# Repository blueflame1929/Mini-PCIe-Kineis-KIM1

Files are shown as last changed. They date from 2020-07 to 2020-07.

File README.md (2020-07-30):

# Mini PCI Express Card / Kinéis KIM1 Satellite Transmitter

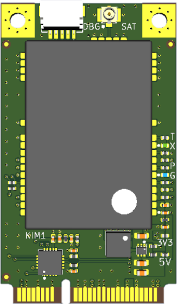
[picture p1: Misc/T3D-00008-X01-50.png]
T3D-00008-X01-50
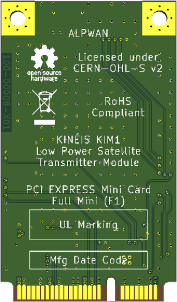
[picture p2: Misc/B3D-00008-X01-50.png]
B3D-00008-X01-50
  

This card is a satellite modem that targets IoT applications. Some IoT applications may require 24/7 worldwide coverage, and cellular networks are not suitable since they may not provide coverage in remote locations, at sea, or at altitude. The only solution in that case is to go with satellite communication through thank to networks such as the ones provided by Kinéis. Available everywhere, low power consumption, simple, reliable and affordable.

Kinéis KIM1 is a low power transmitter module based on ARGOS-2 technology and fully-certified by the CNES. It enables communication with all the Kineis-Argos satellites to provide satellite connectivity and localization for IoT devices. The use of ARGOS RF signals and protocols ensures very low power consumption when sending data from anywhere around the world.

This card makes it easy to add a satellite modem to your projects thanks to it’s mini PCIe form factor and USB 2.0 interface.

more informations see www.kineis.com

# Key features and specifications

BRD-00008-X01-Block-Diagram

- Kinéis KIM1 Satellite Transmitter
- Small lightweight module for embedded applications
- Available everywhere
- RF output power capabilities up to 1W
- Low power consumption
- Frequency range 399.910 - 401.680MHz
- UART AT command interface
- Host interface : USB 2.0 via Mini PCIe socket
- Antenna : external via µ.FL connector (50Ω)

- Power Supply Voltage : +3.3V +/-5%
- Operating Current : 1.2A Transmit
- Form Factor : Mini PCI Express, full size
- Dimensions : 50.95 x 30.00 x 4.15mm
- Weight : TBD
- Operating Temperature Range : -20°C/+55°C
- Storage Temperature Range : -40°C/+85°C
- Humidity : 10% to 90%, non condensing

# Repository Contents

- /documentation : integration manual (with AT commands)
- /hardware : KiCad design files (BRD-00008-X01.zip)
- /hardware/ASY : ASY-00008-X01.zip --> send it to your assembly house
- /hardware/Datasheets
- /hardware/PCB : PCB-00008-X01.zip --> sent it to your pcb manufacturer
- /hardware/SCH : SCH-00008-X01 --> engineering team 

# License information

This product is open source.

Please review the LICENSE.md file for license information.

Distribute as-is, no warranty is given.

# Support

If you have some questions, please contact support(at)alpwan.fr

kicad_logo_small

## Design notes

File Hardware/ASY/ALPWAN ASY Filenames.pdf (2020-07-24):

ALPWAN ASY Filenames.xlsx

Name | Kicad file name or layer name | ALPWAN file name
Top Assembly | F.Fab | TAY-XXXXX-XXX.pdf
Top Solder Paste | xxxx-F_Paste.gbr for the component-side solder paste | TSP-XXXXX-XXX.gbr
Top Placement File | xxxx-top.pos | TPF-XXXXX-XXX.txt
Placement File | xxxx-all.pos | PFE-XXXXX-XXX.txt
Bottom Placement File | xxxx.bottom.pos | BPF-XXXXX-XXX.txt
Bottom Solder Paste | xxxx-B_Paste.gbr for the copper-side solder paste | BSP-XXXXX-XXX.gbr
Bottom Assembly | B.Fab | BAY-XXXXX-XXX.pdf
Schematic | n/a | SCH-XXXXX-XXX.pdf
Bill Of Materials | xxxx.csv (convert to Excel) | BOM-XXXXX-XXX.xlsx
Bill Of Materials | Also available in PDF | BOM-XXXXX-XXX.pdf
Board Mechanical Drawing | Dwgs.User | BMD-XXXXX-XXX.pdf
Top 3D View | n/a | T3D-XXXXX-XXX.png
3D View | n/a | 3DV-XXXXX-XXX.png
Bottom 3D View | n/a | B3D-XXXXX-XXX.png
GERBER file format: | The format used by KiCad Pcbnew is RS274X 4.6, Metric, Leading zero omitted, Abs
20/07/2019 | 1 / 1

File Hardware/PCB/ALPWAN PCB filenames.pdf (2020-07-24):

ALPWAN PCB filenames.xlsx

Layer | Kicad file name or layer name | ALPWAN file name
Top Solder Paste | xxxx-F_Paste.gbr for the component-side solder paste | TSP-XXXXX-XXX.gbr
Top Silk Screen | xxxx-F_SilkS.gbr for the component-side silkscreen markings | TSS-XXXXX-XXX.gbr
Top Solder Mask | xxxx-F_Mask.gbr for the component-side solder mask | TSM-XXXXX-XXX.gbr
Top | xxxx-F_Cu.gbr for the component side | TOP-XXXXX-XXX.gbr
Internal 1 | xxxx-In1.Cu.gbr | IL1-XXXXX-XXX.gbr
Internal 2 | xxxx-In2.Cu.gbr | IL2-XXXXX-XXX.gbr
Internal n | xxxx-Inn.Cu.gbr | ILn-XXXXX-XXX.gbr
Bottom | xxxx-B_Cu.gbr for the copper side | BOT-XXXXX-XXX.gbr
Bottom Solder Mask | xxxx-B_Mask.gbr for the copper-side solder mask | BSM-XXXXX-XXX.gbr
Bottom Silk Screen | xxxx-B_SilkS.gbr for the copper-side silkscreen markings | BSS-XXXXX-XXX.gbr
Bottom Solder Paste | xxxx-B_Paste.gbr for the copper-side solder paste | BSP-XXXXX-XXX.gbr
GERBER file format: | The format used by KiCad Pcbnew is RS274X 4.6, Metric, Leading zero omitted, Abs
Drill File | xxxx.drl | DRL-XXXXX-XXX.exc
Drill Map | xxxx-drl_map.pdf | MDD-XXXXX-XXX.pdf
Drill Report | xxxx-drl.rpt | DRL-XXXXX-XXX.rpt
EXCELLON file format : | The format used by KiCad Pcbnew is EXCELLON 3.3, Metric, Leading zero omitted, Abs
PCB Characteristics | see MDD-XXXXX-XXX.pdf
PCB Stack_Up | see MDD-XXXXX-XXX.pdf
Controlled Impedance | Kicad PCB Calculator | IMP-XXXXX-XXX.docx
Controlled Impedance | Also available in PDF | IMP-XXXXX-XXX.pdf
20/07/2019 | 1 / 1

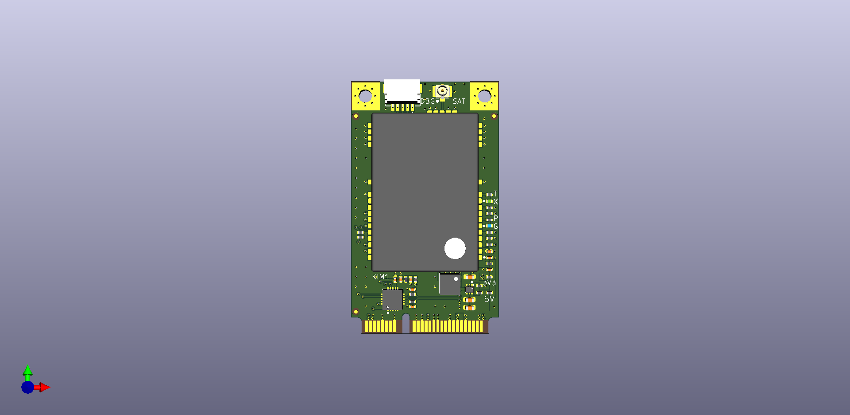
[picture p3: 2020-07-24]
Hardware/ASY/T3D-00008-X01.png

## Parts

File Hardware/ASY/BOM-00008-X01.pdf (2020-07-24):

ALPWAN | PCI Express Mini Card / Kinéis KIM1 | BOM-00008-X01.xlsx
Internal P/N | Quantity Per PCB | References | Description | Manufacturer | Manufacturer P/N
100-00008-X01 | 1 | PCB1 | PCB, Material : FR4 150 TG, Layers : 4 , Dimension : 30.00 x 50.95 mm, Thickness : 1.00 mm, Finition : Chemical NI/Au | TBD | TBD
105-00001-M01 | 4 | R1 R7 R10 R13 | Thick Film Chip Resistor 0R, Jumper, 0.1W, 50V, 1A, -55°C/+155°C, SMD 1005M | PANASONIC | ERJ-2GE0R00
105-00002-M01 | 2 | R2-R3 | Thick Film Chip Resistor 27R, ±1%, 0.1W, 50V, ±100ppm/°C, -55°C/+155°C, SMD 1005M | PANASONIC | ERJ-2RKF27R0
105-00006-M01 | 3 | R5 R9 R15 | Thick Film Chip Resistor 100K, ±1%, 0.1W, 50V, ±100ppm/°C, -55°C/+155°C, SMD 1005M | PANASONIC | ERJ-2RKF1003
105-00050-M01 | 3 | R4 R12 R16 | Thick Film Chip Resistor 665R, ±1%, 0.1W, 50V, ±100ppm/°C, -55°C/+155°C, SMD 1005M | PANASONIC | ERJ-2RKF6650
110-00001-I01 | 2 | C5 C8 | Ceramic Chip Capacitor 10µF, ±20%, 10V, X5R, -55°C/+85°C, SMD 1005M | SAMSUNG | CL05A106MP8NUB8
110-00009-M01 | 2 | C4 C7 | Ceramic Chip Capacitor 100nF, ±10%, 16V, X7R, -55°C/+125°C, SMD 1005M | MURATA | GRM155R71C104KA88
110-00010-M01 | 2 | C3 C6 | Ceramic Chip Capacitor 10nF, ±10%, 25V, X7R, -55°C/+125°C, SMD 1005M | MURATA | GRM155R71E103KA01
110-00024-M01 | 2 | C1-C2 | Ceramic Chip Capacitor 47pF, ±5%, 25V, COG NPO, -55°C/+125°C, SMD 1005M | MURATA | GRM1555C1E470JA01
110-00075-I01 | 1 | C9 | Ceramic Chip Capacitor 10µF ±20%, 10Vdc, X5R, -55°C/+85°C, SMD 1608M | MURATA | GRM188R61A106MAAL
110-00076-I01 | 2 | C10-C11 | Ceramic Chip Capacitor 22µF ±20%, 10Vdc, X5R, -55°C/+85°C, SMD 1608M | MURATA | GRM188R61A226ME15
115-00026-A01 | 1 | L1 | WE-MAPI Shielded Power Inductor, 1µH ±20%, IR 7.4A, RDC 11.6mΩ, -40°C/+125°C, SMD 4.1x4.1x3.1mm | WURTH ELEKTRONIK | 74438357010
130-00001-I02 | 1 | LD1 | LED Blue, 2.9V, 5mA, 470nm, 17mcd, -40°C/+85°C, SMD 1006M | ROHM | SMLP13BC8T
130-00002-I02 | 1 | LD2 | LED Green, 2.2V, 20mA, 560nm, 13mcd, -40°C/+85°C, SMD 1006M | ROHM | SML-P13PT
140-00001-I01 | 1 | U1 | USB to Full Handshake UART, -40°C/+85°C, SMD QFN-20 (4X4) | FTDI | FT231XQ
140-00050-A01 | 1 | U2 | 3.7A Boost Converter with 0.5V Ultra-low Input Voltage, -40°C/+125°C, SMD SOT-563 (D 1.6x1.6x0.6mm / P 0.6mm) | TEXAS INSTRUMENTS | TPS61023DRL
155-00002-M01 | 2 | FB1-FB2 | Chip Ferrite Bead, 33ohm ±25% @ 100MHZ, 3A, 0.022ohm, -55°C/+125°C, SMD 1005M | MURATA | BLM15PX330SN1
160-00001-I01 | 1 | J2 | U.FL Series, Ultra Small Surface Mount Coaxial Connector, Receptacle, DC to 6GHz, 50Ω, -40°C/+90°C, SMD | HIROSE | U.FL-R-SMT-1
160-00054-E01 | 1 | J3 | 1.0mm Pitch SH Shrouded Header, Right Angle, 5 Circuits, -25°C/+85°C, SMD | JST | SM05B-SRSS-TB
195-00011-C01 | 1 | MOD1 | Low Power Satellite Transmitter Module, ARGOS-2 Technology, -20°C/+55°C, SMD 31.2x21x3.5mm | KINEIS | KIM1
Do Not Fit | 4 | R6 R8 R11 R14
24/07/2020 | 1 / 1

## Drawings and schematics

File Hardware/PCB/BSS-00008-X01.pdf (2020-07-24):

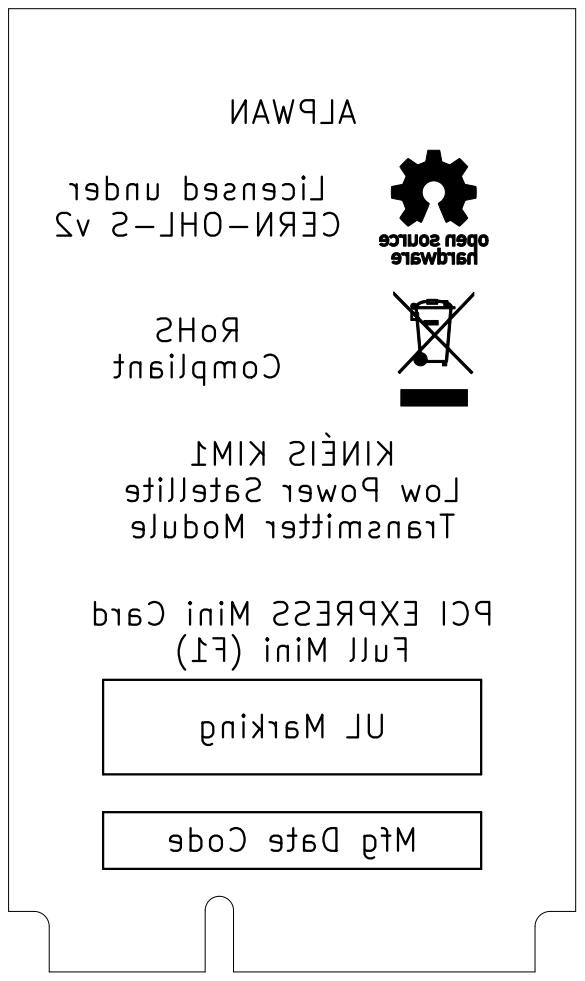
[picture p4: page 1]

Full Mini (F1) RoHS Compliant Licensed under CERN-OHL-S v2 KINÉIS KIM1 Low Power Satellite Transmitter Module ALPWAN

Mfg Date Code UL Marking PCI EXPRESS Mini Card

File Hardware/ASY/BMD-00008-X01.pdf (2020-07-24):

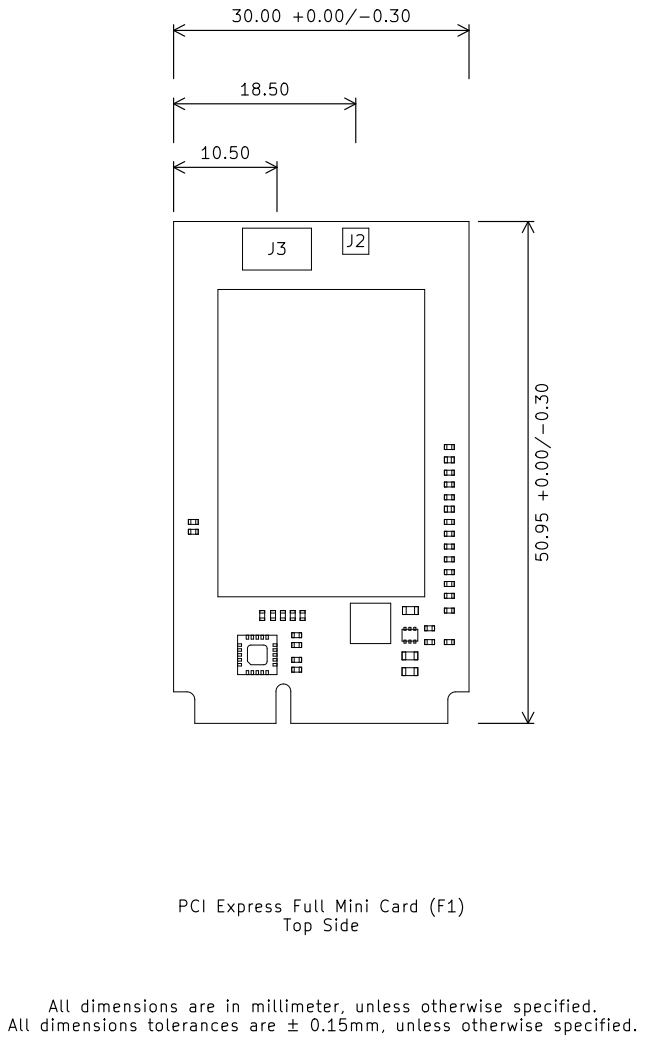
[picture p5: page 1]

Rev : X01 Size : A4 Sheet : 1/1 Product : PCI Express Full Mini Card (F1) / KIM1 Sheet name :

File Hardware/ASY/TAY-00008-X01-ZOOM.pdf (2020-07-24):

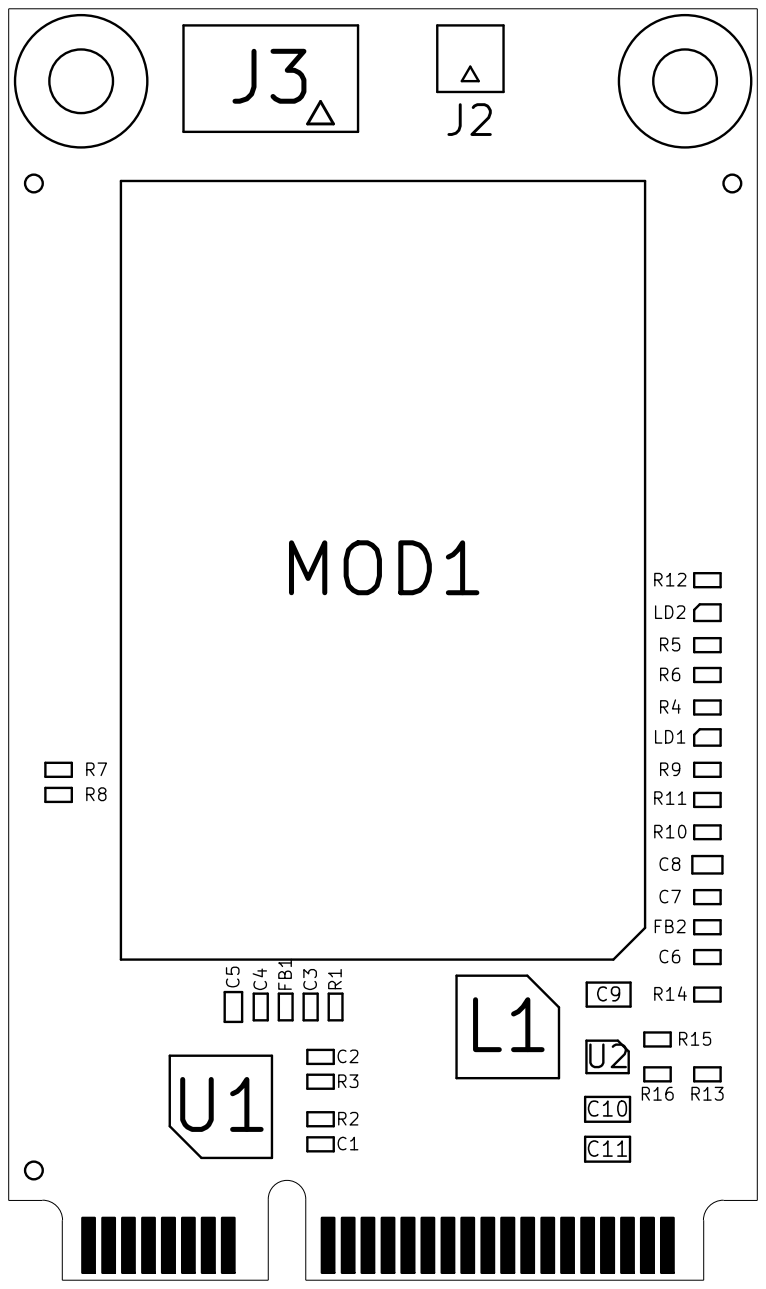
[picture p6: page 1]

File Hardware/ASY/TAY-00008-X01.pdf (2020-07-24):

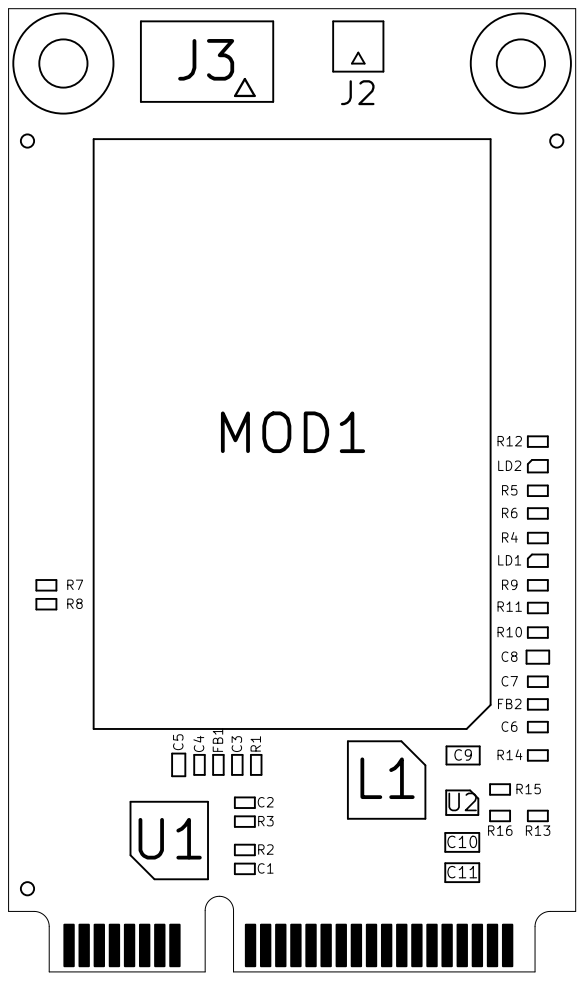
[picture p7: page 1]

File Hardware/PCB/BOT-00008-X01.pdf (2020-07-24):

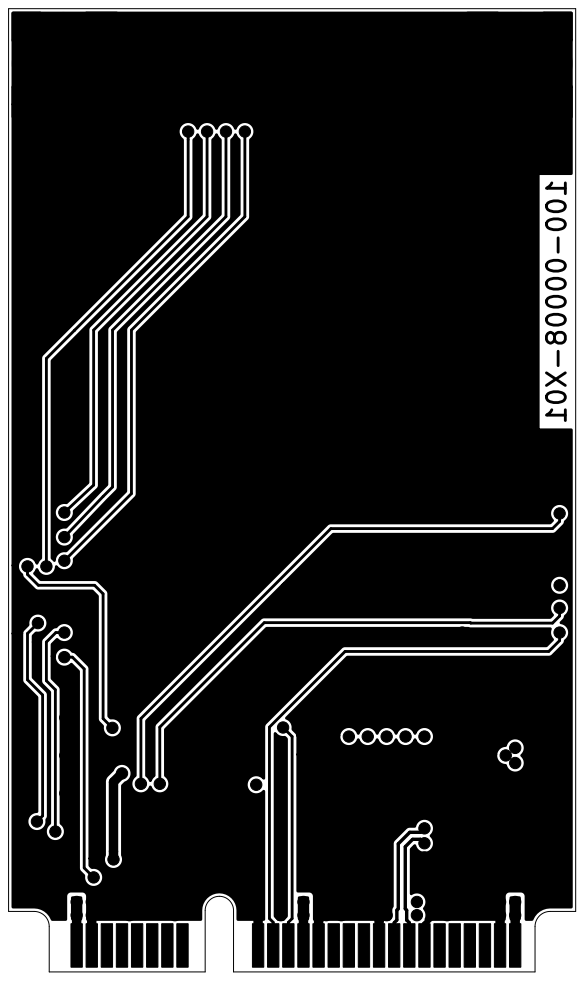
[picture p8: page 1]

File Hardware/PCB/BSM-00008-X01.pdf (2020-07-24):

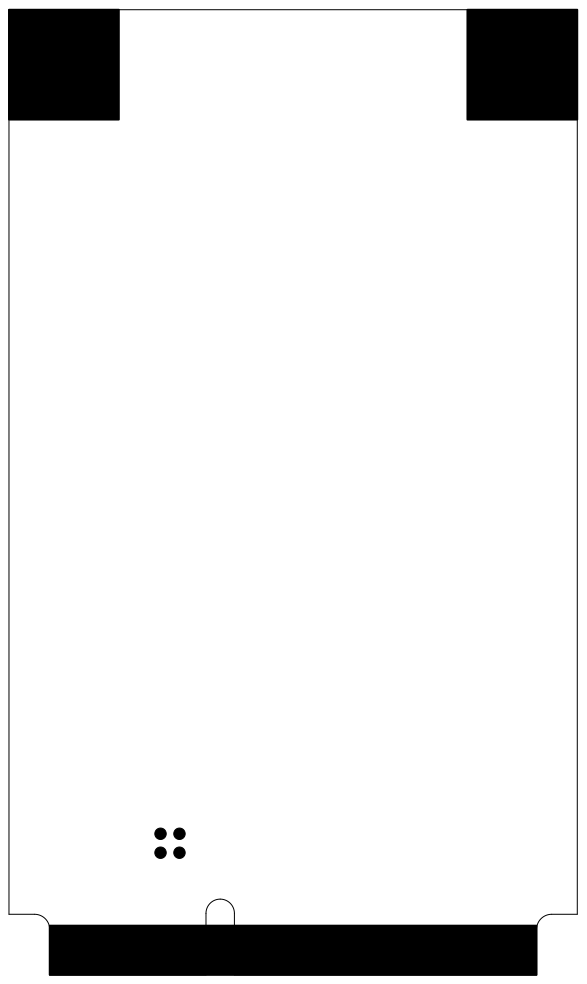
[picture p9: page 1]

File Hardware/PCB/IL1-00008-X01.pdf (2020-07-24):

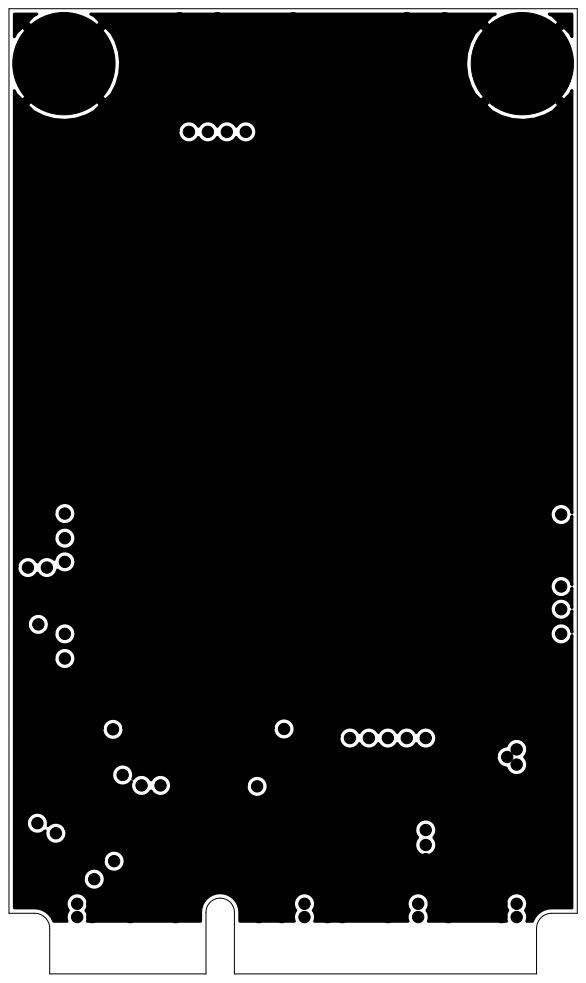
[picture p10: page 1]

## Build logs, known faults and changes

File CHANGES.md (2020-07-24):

# History

- Version X01 : initial release / Stéphane David @ ALPWAN.
